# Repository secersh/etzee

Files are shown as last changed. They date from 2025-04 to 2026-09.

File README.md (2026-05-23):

# etzee

etzee is an open modular input-device ecosystem. It combines keyboards, utility modules, magnetic pogo-pin connectors, local displays, haptics, and firmware that can discover and communicate across connected modules.

The project is early and hardware-heavy. The current active board is B11; M0 and M9 are planned modules.

## Devices

| Device | Type | Status | Notes |
|---|---|---|---|
| B11 | Primary keyboard board | Active | Split or monoblock keyboard, 5/6 columns per half, switch-family PCB variants |
| M0 | Module | Planned | USB-C module with haptic dial and round touch display |
| M9 | Module | Planned | USB-C 3x3 mechanical keypad with display |

## B11

B11 is the first primary etzee keyboard. Current design goals:

- split or monoblock use
- Bluetooth-first firmware target
- hot-swappable switch carriers
- integrated dot-matrix display on switch plates
- south-facing per-key LEDs
- magnetic pogo-pin module connectors
- 5-column and 6-column half variants
- MX, Choc v2, and KS-33 switch-family variants
- generated KiCad PCB files from tracked MCAD-derived outlines

Current B11 docs:

- [switch compatibility](docs/b11/switch-compatibility.md)
- [switch profiles](docs/b11/switch-profiles.md)
- [keycap compatibility](docs/b11/keycap-compatibility.md)

## Repository Layout

```text
.github/workflows/          GitHub Actions workflows
docs/b11/                   B11 hardware compatibility and profile docs
docs/firmware/              firmware and protocol docs
firmware/                   firmware workspaces
hardware/b11/ecad/          B11 KiCad projects and generated boards
hardware/b11/mcad/          B11 MCAD export config and PCB outlines
hardware/b11/tools/         B11 PCB generation/update tools
hardware/tools/             shared hardware tooling
lib/                        shared KiCad footprints, 3D models, datasheets
```

## Generated PCB Workflow

B11 generated boards are updated through one batch script:

```sh
/Applications/KiCad/KiCad.app/Contents/Frameworks/Python.framework/Versions/Current/bin/python3 hardware/b11/tools/update-pcbs.py --manufacturer jlcpcb --dry-run
```

Remove `--dry-run` to update generated PCB files locally. The updater can generate PCB outlines, place switch sockets, place switch LEDs, place display LEDs, apply manufacturer stackups, and generate manufacturer design rules.

Current generated B11 PCB variants:

| Family | Columns | Boards |
|---|---|---|
| MX | 5, 6 | `LSP`, `RSP`, `LSC`, `RSC` |
| CHOC-V2 | 5, 6 | `LSP`, `RSP`, `LSC`, `RSC` |
| KS-33 | 5, 6 | `LSP`, `RSP`, `LSC`, `RSC` |

Board names use:

```text
ETZ-B11-{board_code}-{columns}-{switch_family}.kicad_pcb
```

Example:

```text
ETZ-B11-LSP-5-KS-33.kicad_pcb
```

## MCAD Exports

B11 MCAD export inputs are defined in [hardware/b11/mcad/parts.yaml](hardware/b11/mcad/parts.yaml). The GitHub workflow exports common parts once and matrix parts once per board variant:

- `5-MX`, `6-MX`
- `5-CHOC-V2`, `6-CHOC-V2`
- `5-KS-33`, `6-KS-33`

PCB outline DXFs live under:

```text
hardware/b11/mcad/pcb-outlines/{MX,CHOC-V2,KS-33}/
```

## Firmware

Firmware is based around ZMK-compatible targets. The htoyto protocol is the project-specific communication concept for inter-module discovery and messaging.

- [htoyto protocol overview](docs/firmware/htoyto.md)

## Contributing

See [CONTRIBUTING.md](CONTRIBUTING.md). The short version: keep generated files reproducible, keep hardware changes scoped, and run the relevant dry-runs before opening a pull request.

For discussion and implementation feedback, join the etzee Discord:

https://discord.gg/y3pcSCghcg

## License

This repository uses different open licenses for different material types. See [LICENSE.md](LICENSE.md) for the full licensing map.

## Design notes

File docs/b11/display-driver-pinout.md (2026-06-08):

<!-- SPDX-License-Identifier: CC-BY-4.0 -->

# B11 Display Driver Pinout

The B11 display matrix uses an IS31FL3741A LED driver and a 39 x 7 active LED
matrix. The driver supports 39 CS lines and 9 SW lines; `SW8` and `SW9` are
unused on the rev1 DSP module.

## IS31FL3741A Matrix Pins

The IS31FL3741A QFN-60 matrix pins are clustered like this:

| Package area | Pins | Nets |
| --- | --- | --- |
| Left/top side | 1-6 | `LED_CS34` .. `LED_CS39` |
| Bottom side | 16-24 | `LED_SW1` .. `LED_SW9` |
| Bottom/right corner | 26-30 | `LED_CS1` .. `LED_CS5` |
| Right side | 31-35, 37-45 | `LED_CS6` .. `LED_CS19` |
| Top/right side | 46-54, 56-60 | `LED_CS20` .. `LED_CS33` |

Pins `7`-`15`, `25`, `36`, `55`, and exposed pad `61` are driver control,
power, or ground pins and are not routed through the display board
castellations.

## Display Module Castellated Pads

The rev1 display LED matrix board uses 46 castellated LED pads along the two
long side edges. These are board-to-board solder pads, not a separate
connector. Pad numbers walk counter-clockwise around the side castellations:

| Edge pads | Physical group | Nets |
| --- | --- | --- |
| 1-11 | left/top | `LED_CS29` .. `LED_CS19` |
| 12-23 | left/bottom | `LED_CS18`, `LED_CS16` .. `LED_CS6` |
| 24-35 | right/bottom | `LED_CS5` .. `LED_CS1`, `LED_SW7` .. `LED_SW1` |
| 36-46 | right/top | `LED_CS17`, `LED_CS39` .. `LED_CS30` |

This package-oriented map is intended to make SP-side fanout from the
IS31FL3741A easier. The map is mirrored left-to-right so the driver can sit
near the center/right of the SP board and fan out mostly to the nearer
right-side castellated groups.

The ALS signals use four separate top-edge castellated pads, left-to-right:
`ALS_VDD`, `ALS_SCL`, `ALS_SDA`, `ALS_GND`.

The source of truth for generated tooling is
`hardware/b11/tools/placement/display_pinout.py`.

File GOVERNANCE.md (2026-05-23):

# Governance

etzee is maintained by its founders as peers. Current founder-maintainers are listed in `MAINTAINERS.md`.

## Decision Making

Major project decisions are made by founder consensus. Decisions are made pragmatically around:

- reproducible hardware and firmware outputs
- manufacturability
- maintainable tooling
- clear licensing and attribution
- compatibility with the current B11, M0, and M9 roadmap

Maintainers may decline or defer changes that are useful but outside the current project scope.

## Founder-Maintainer Responsibilities

Founder-maintainers jointly share responsibility for:

- reviewing and merging pull requests
- keeping generated files reproducible
- setting release and manufacturing direction
- product direction
- hardware and firmware architecture
- licensing
- enforcing the code of conduct
- coordinating security disclosures

Specific implementation areas may be handled by whoever has the relevant context for that change.

## Contributor Responsibilities

Contributors are expected to:

- keep pull requests focused
- explain hardware, firmware, or tooling tradeoffs clearly
- update docs when behavior or interfaces change
- preserve license and attribution notices

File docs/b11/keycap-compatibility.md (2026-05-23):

# B11 Keycap Compatibility

B11 keycaps must use MX-compatible stems. This keeps the keycap interface common across the supported switch families, including MX, Choc v2, and KS-33 variants.

| Keycap requirement | Value |
|---|---|
| Stem | MX-compatible cross stem |
| Switch grid pitch | 19.2 mm x 19.2 mm |
| Supported B11 switch families | `MX`, `CHOC-V2`, `KS-33` |

Low-profile switch variants can still use MX-stem keycaps, but cap height, skirt clearance, and travel clearance need to be checked against the selected switch family and enclosure geometry.

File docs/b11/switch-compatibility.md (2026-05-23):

# B11 Switch Compatibility

B11 currently generates separate PCB variants per switch family. The family name is used in ECAD board paths, MCAD PCB outline paths, and MCAD release artifact suffixes.

| Switch family | Compatible switches | Profile | Socket footprint | PCB family |
|---|---|---|---|---|
| MX | Cherry MX and common MX-compatible switches from Kailh, Gateron, and others | Normal | `PG151101S11` | `MX` |
| CHOC-V2 | Kailh Choc v2 / PG1353 | Low | `CPG135001S30` | `CHOC-V2` |
| KS-33 | Gateron KS-33 / KS-2P02B01-01-a | Low | `KS-2P02B01-01-a` | `KS-33` |

Generated B11 switch PCB variants use this layout:

| Family | ECAD boards | PCB outlines | MCAD artifact suffixes |
|---|---|---|---|
| MX | `hardware/b11/ecad/MX/` | `hardware/b11/mcad/pcb-outlines/MX/` | `5-MX`, `6-MX` |
| CHOC-V2 | `hardware/b11/ecad/CHOC-V2/` | `hardware/b11/mcad/pcb-outlines/CHOC-V2/` | `5-CHOC-V2`, `6-CHOC-V2` |
| KS-33 | `hardware/b11/ecad/KS-33/` | `hardware/b11/mcad/pcb-outlines/KS-33/` | `5-KS-33`, `6-KS-33` |

All current B11 switch variants use a 19.2 mm x 19.2 mm switch grid pitch. Switch-specific footprints, plate geometry, and board stackups are handled by the B11 PCB generation tools.

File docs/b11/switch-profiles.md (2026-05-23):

# B11 Switch Profiles

Mechanical stackup parameters per B11 switch family. These values drive the OnShape switch-family configurations and the generated PCB variants.

| Parameter | MX | CHOC-V2 | KS-33 |
|---|----|---|---|
| Switch plate mechanical thickness (mm) | 1.5-1.9 | 1.65 | 1.2 |
| Switch plate PCB order thickness (mm) | 1.6 | 1.6 | 1.2 |
| Carrier board mechanical thickness (mm) | 1.6 | 1.6 | 1.5-1.6 |
| Carrier board PCB order thickness (mm) | 1.6 | 1.6 | 1.6 |
| Top plate to top carrier offset (mm) | 5.0 | 2.2 | 2.5 |

The PCB order thickness rows are the rounded manufacturer thicknesses used by `hardware/b11/tools/config.py`.

Offset is the vertical distance from the top surface of the switch plate to the top surface of the carrier board.

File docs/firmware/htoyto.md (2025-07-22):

# htoyto Protocol – Integration Overview

This document outlines the detailed structure for integrating the **htoyto** protocol ("hello to you too") into a ZMK-based firmware stack. The protocol enables UART-based inter-module communication between a sender and one or more receivers, with rising-edge interrupts for handshake initiation.

> ℹ️ Note: This implementation is ZMK-specific and relies on ZMK's event system. If you plan to reuse `htoyto` in pure Zephyr projects, consider creating a separate generic backend.

---

## 🧽 Node Roles Overview

* `origin` — initiates communication (**1×** occurrence per htoyto chain)
* `bridge` — relays data between nodes (**0 or more** per chain)
* `terminal` — receives and handles commands (**1×** occurrence per chain)

### Visual Topology

```mermaid
graph LR
    Origin((origin)) -->|UART + dR| B1{{bridge}}
    B1 -->|UART + dR| B2{{bridge}}
    B2 -->|UART| Terminal((terminal))
```

> 💡 The topology follows a left-to-right convention. Only the left-most node requires a `dr-gpios` interrupt pin. Bridges pass through data and may generate their own responses.

---

## 📦 Data Frames

### Supported Packet Types

| Frame | Description |
| --- | --- |
| `HLO <node_id>` | Initiates handshake from origin |
| `IAM <node_id>` | Identity declaration from terminal or bridge |
| `EST <node_id>` | Establish link — sent by both origin and terminal to confirm connection |
| `DKW <message>` | Rejection — origin to terminal with reason (e.g., unknown node) |
| `TLK <source,target,data>` | Application-level message |
| `ACK <ref>` (optional) | Acknowledgment of a `TLK` frame |

> 💡 `DKW` is always sent by the origin to a node it refuses to accept. `EST` completes a handshake only if echoed from both sides.

---

## 🤝 Handshake: Node Lifecycle

### ✅ Successful Node Adding

**Sequence (Origin ➔ Terminal)**

1. Origin detects rising edge on `dR` line
2. Origin sends: `HLO <origin_id>`
3. Terminal responds: `IAM <terminal_id>`
4. Origin sends: `EST <origin_id>`
5. Terminal sends: `EST <terminal_id>`

**Emitted Events**

* Origin emits: `HTOYTO_EVENT_NODE_ADDED`
* Terminal emits: `HTOYTO_EVENT_NODE_ADDED`

---

### ✅ Successful Node Removal

**Sequence (Origin ➔ Terminal)**

1. Origin detects **falling edge** on `dR` line (physical disconnect or deliberate teardown)

**Emitted Events**

* Origin emits: `HTOYTO_EVENT_NODE_REMOVED`
* Terminal emits: `HTOYTO_EVENT_NODE_REMOVED`

---

### ❌ Failure: Terminal Not Supported

**Sequence**

1. Origin sends: `HLO <origin_id>`
2. Terminal responds: `IAM <terminal_id>`
3. Origin sends: `DKW <reason>`

**Emitted Events**

* Origin emits: `HTOYTO_EVENT_NODE_ADDED_FAILED`
* Terminal emits: `HTOYTO_EVENT_NODE_ADDED_FAILED`

---

### ❌ Failure: Timeout

#### Sub-case A: No IAM from Terminal

* Origin sends: `HLO <origin_id>`
* ⏱️ Terminal does not respond with `IAM` in \[xx ms]

**Emitted Events**

* Origin emits: `HTOYTO_EVENT_NODE_ADDED_FAILED`
* Terminal emits: `HTOYTO_EVENT_NODE_ADDED_FAILED`

#### Sub-case B: No EST from Terminal

* Origin sends: `EST <origin_id>`
* ⏱️ Terminal does not respond with `EST <terminal_id>` in \[xx ms]

**Emitted Events**

* Origin emits: `HTOYTO_EVENT_NODE_ADDED_FAILED`
* Terminal emits: `HTOYTO_EVENT_NODE_ADDED_FAILED`

#### Sub-case C: No EST from Origin

* Terminal sends: `IAM <terminal_id>`
* ⏱️ Origin does not respond with `EST <origin_id>` in \[xx ms]

**Emitted Events**

* Origin emits: `HTOYTO_EVENT_NODE_ADDED_FAILED`
* Terminal emits: `HTOYTO_EVENT_NODE_ADDED_FAILED`

---

## 🗂️ Project Structure

### 1. Device Tree Files

#### DTS Overlay

* **Path:** `app/boards/arm/etzee/left.overlay` (origin) and `app/boards/arm/etzee/right.overlay` (terminal)
* **Purpose:** Defines `htoyto` device nodes per side

```dts
/ {
    htoyto0: htoyto {
        compatible = "etzee,htoyto-zmk";
        status = "okay";
        role = "origin"; /* on left side */
        uart = <&uart0>;
        dr-gpios = <&gpio1 11 (GPIO_ACTIVE_HIGH | GPIO_PULL_DOWN)>;
        node-id = "left_leg";
    };
};
```

```dts
/ {
    htoyto0: htoyto {
        compatible = "etzee,htoyto-zmk";
        status = "okay";
        role = "terminal"; /* on right side */
        uart = <&uart0>;
        node-id = "right_leg";
    };
};
```

#### YAML Binding

* **Path:** `app/dts/bindings/htoyto/htoyto.yaml`
* **Purpose:** Describes properties (`uart`, `dr-gpios`, `role`, etc.)

```yaml
compatible: "etzee,htoyto-zmk"

include: base.yaml

properties:
  uart:
    type: phandle
    required: true
    description: UART device used for htoyto communication

  dr-gpios:
    type: phandle-array
    required: false
    description: >
      GPIO pin used for rising edge interrupt (dR line).
      Required only for origin and bridge roles.
      Although only one pin is used, Zephyr requires 'gpios' to be plural
      because the property value is a structured array of controller, pin, and flags.

  role:
    type: string
    required: true
    enum:
      - origin
      - bridge
      - terminal
    description: >
      Role of the htoyto node:
        - origin: initiates communication (left-facing connection)
        - bridge: forwards from left to right (middle node)
        - terminal: receives commands (right-facing connection)

  node-id:
    type: string
    required: true
    description: >
      A unique identifier for the node in the htoyto network.
      Used to route or trigger logic based on physical orientation or connection topology.
```

> 💡 In physical design, a node with pogo pins on **both sides** can act as a **bridge**: a terminal on the left and an origin on the right. This makes `node-id` essential for identification and orchestration.

---

### 2. C Header and Source Files

#### Header File

* **Path:** `app/include/htoyto/htoyto.h`
* **Purpose:** Public API, status enums, macros, event declarations

#### Source File

* **Path:** `app/src/htoyto/htoyto.c`
* **Purpose:** Handles init, handshake logic, GPIO ISR, UART read/write, event emission, and command callback registration

---

### 3. Kconfig Integration

#### Kconfig File

* **Path:** `app/src/htoyto/Kconfig`

```kconfig
config HTOYTO_ENABLED
    bool "Enable htoyto protocol"
    default y
    help
      Enables the etzee htoyto protocol support for UART-based inter-module communication.
```

#### Include in Tree

* **Path:** `app/src/Kconfig`

```kconfig
source "src/htoyto/Kconfig"
```

---

### 4. CMake Integration

#### Main Include

* **Path:** `app/src/CMakeLists.txt`

```cmake
add_subdirectory(htoyto)
```

#### htoyto-specific File

* **Path:** `app/src/htoyto/CMakeLists.txt`

```cmake
zephyr_library_sources(htoyto.c events/event.c)
zephyr_include_directories(${CMAKE_CURRENT_SOURCE_DIR}/../../include)
```

---

### 5. Event System

#### Event Header

* **Path:** `app/include/htoyto/events/event.h`
* **Purpose:** Defines `htoyto_event` structure and event types:

```c
enum htoyto_event_type {
    HTOYTO_EVENT_NODE_ADDED,
    HTOYTO_EVENT_NODE_ADDED_FAILED,
    HTOYTO_EVENT_NODE_REMOVED,
    HTOYTO_EVENT_TLK_RECEIVED,
    HTOYTO_EVENT_ACK_RECEIVED,
    HTOYTO_EVENT_ACK_TIMEOUT
};
```

These events allow communication and state changes to propagate across the system. You may attach listeners to trigger animation, sound, or haptic behavior via a story board system.

---

### 6. Board Setup (Custom Board)

If building a custom board:

* Use `left.overlay` and `right.overlay` under `app/boards/arm/etzee/`
* Add UART, GPIO, and htoyto config to corresponding `.conf` files

---

### 7. Build Config

#### Conf File

* **Path:** `app/boards/arm/etzee/<left|right>.conf`

```conf
CONFIG_SERIAL=y
CONFIG_UART_INTERRUPT_DRIVEN=y
CONFIG_HTOYTO_ENABLED=y
CONFIG_HTOYTO_UART_RX_TIMEOUT_MS=100
CONFIG_HTOYTO_HANDSHAKE_TIMEOUT_MS=200
CONFIG_HTOYTO_MAX_NODE_ID_LENGTH=16
```

---

### ✅ Summary of File Locations

| Type | Path | |
| --- | --- | - |
| DTS Overlay | `app/boards/arm/etzee/left.overlay`, `right.overlay` | |
| YAML Binding | `app/dts/bindings/htoyto/htoyto.yaml` | |
| Header File | `app/include/htoyto/htoyto.h` | |
| Source File | `app/src/htoyto/htoyto.c` | |
| Kconfig | `app/src/htoyto/Kconfig` | |
| CMakeLists.txt | `app/src/htoyto/CMakeLists.txt` | |
| Event Header | `app/include/htoyto/events/event.h` | |
| Event Source | `app/src/htoyto/events/event.c` | |
| Build Config | `app/boards/arm/etzee/<left`, `right>.conf` | |

---

## 🔮 Future Expansion: Story Board Engine

You plan to integrate a second hardware module (dot matrix display, ambient light sensor, beeper) that reacts to htoyto events. A third software component — the **story board engine** — will:

* React to `htoyto_event` events (e.g., `NODE_ADDED`)
* Trigger and play storyboards, defined as animations (with keyframes) + optional audio or haptic effects
* Tailor the experience depending on the `node-id`

This system will allow rich interactions like:

* 🎮 Playing light/audio animations when a certain module connects
* 🎧 Triggering beeps or tones synced to keyframe animation
* 🪏 Optionally driving haptics to complete the effect

This design allows creative UI/UX behaviors inside the firmware, making every module connection feel alive.

Stay tuned for a dedicated story board architecture document.

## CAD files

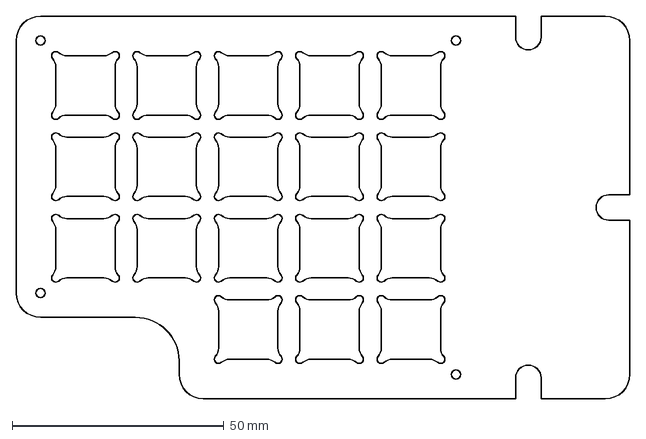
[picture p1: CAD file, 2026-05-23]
hardware/b11/mcad/pcb-outlines/CHOC-V2/ETZ-B11-LSP-5-CHOC-V2.dxf
144.7 x 90.2 mm

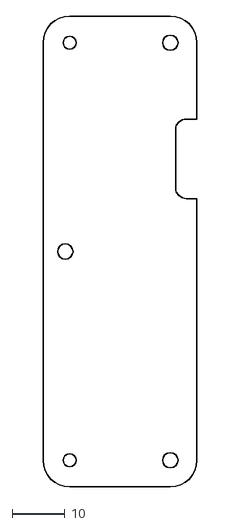
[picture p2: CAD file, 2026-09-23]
hardware/b11/mcad/pcb-outlines/common/ETZ-B11-RLB.dxf
29.0 x 88.8

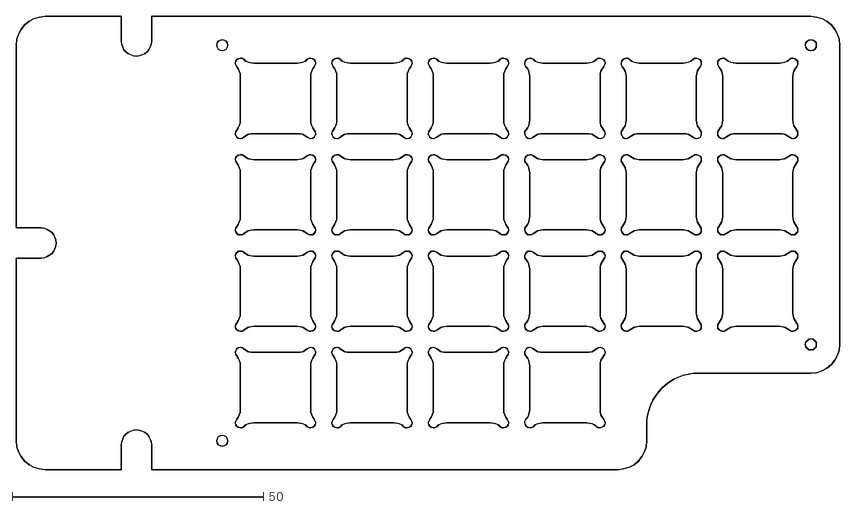
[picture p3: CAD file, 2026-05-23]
hardware/b11/mcad/pcb-outlines/KS-33/ETZ-B11-RSP-6-KS-33.dxf
163.9 x 90.2

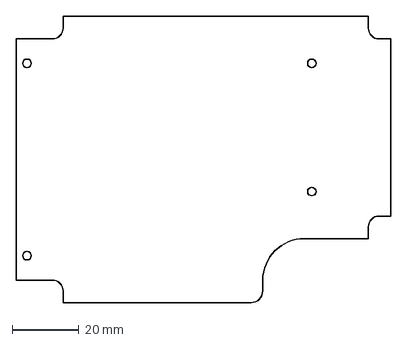
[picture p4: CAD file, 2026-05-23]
hardware/b11/mcad/pcb-outlines/MX/ETZ-B11-RSC-5-MX.dxf
112.3 x 85.8 mm

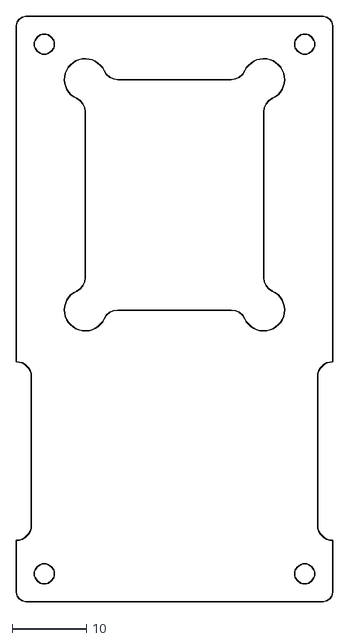
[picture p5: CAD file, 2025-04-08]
manufacturing/Keyboard parts - Display PCB.dxf
42.5 x 78.7

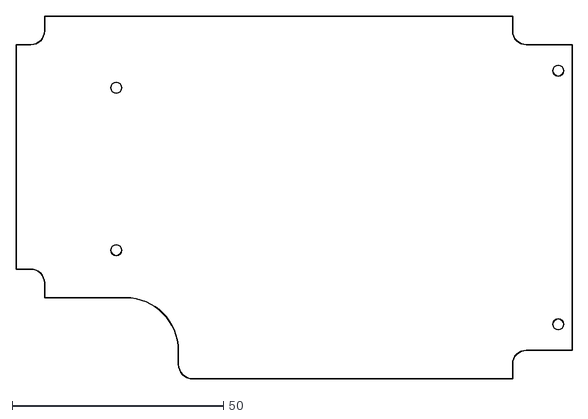
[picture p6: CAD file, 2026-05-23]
hardware/b11/mcad/pcb-outlines/CHOC-V2/ETZ-B11-LSC-6-CHOC-V2.dxf
131.5 x 85.8

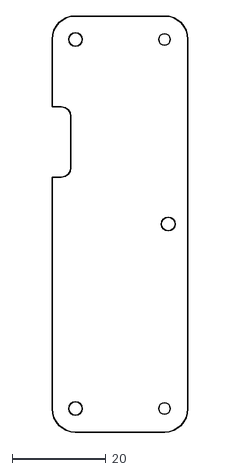
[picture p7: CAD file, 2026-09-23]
hardware/b11/mcad/pcb-outlines/common/ETZ-B11-LLB.dxf
29.0 x 88.8

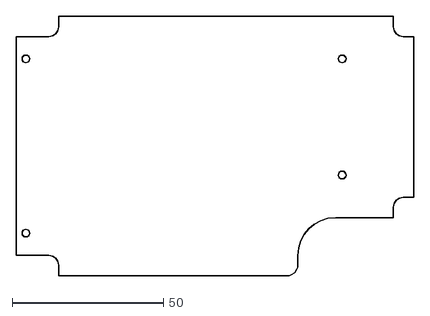
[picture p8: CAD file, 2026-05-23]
hardware/b11/mcad/pcb-outlines/MX/ETZ-B11-RSC-6-MX.dxf
131.5 x 85.8

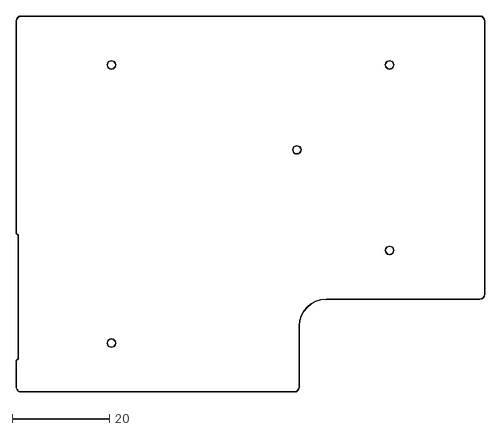
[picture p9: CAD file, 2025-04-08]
manufacturing/Keyboard parts - R PCB.dxf
96.3 x 77.2

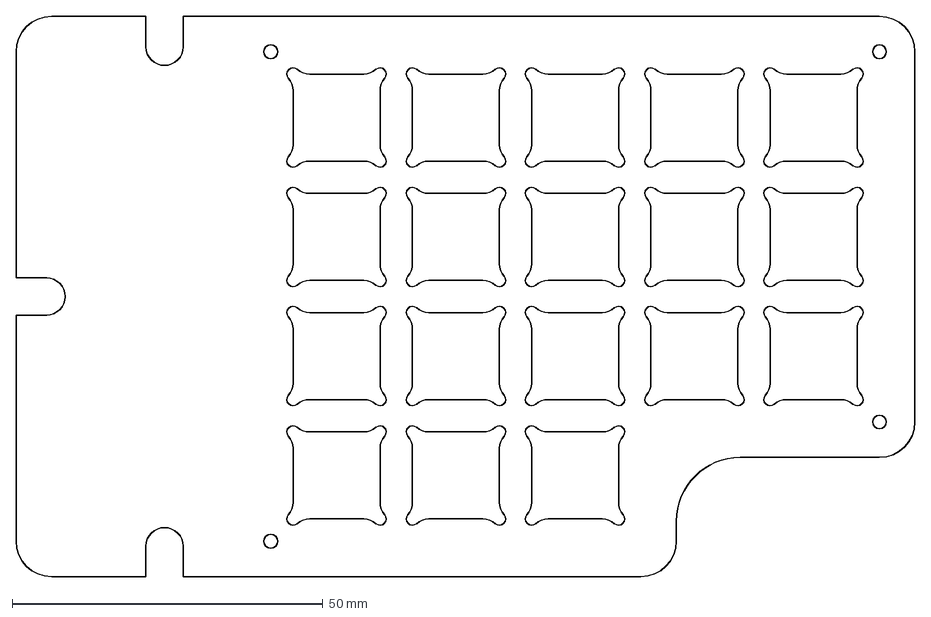
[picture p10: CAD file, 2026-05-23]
hardware/b11/mcad/pcb-outlines/CHOC-V2/ETZ-B11-RSP-5-CHOC-V2.dxf
144.7 x 90.2 mm

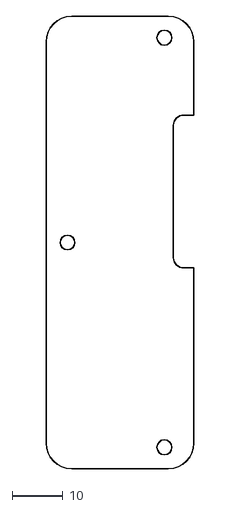
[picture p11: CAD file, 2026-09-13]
hardware/b11/mcad/pcb-outlines/common/ETZ-B11-LGB-R.dxf
29.0 x 88.8

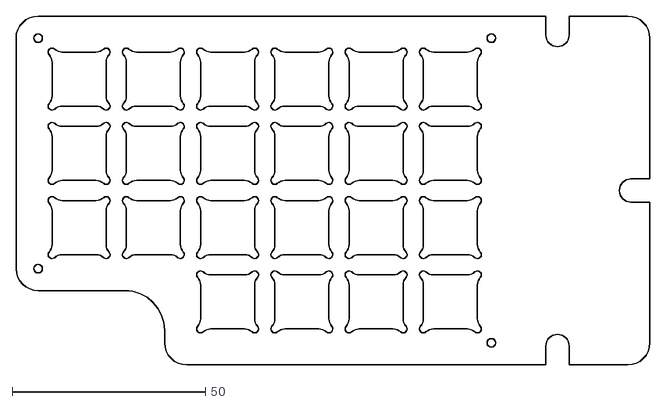
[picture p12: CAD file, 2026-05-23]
hardware/b11/mcad/pcb-outlines/MX/ETZ-B11-LSP-6-MX.dxf
163.9 x 90.2

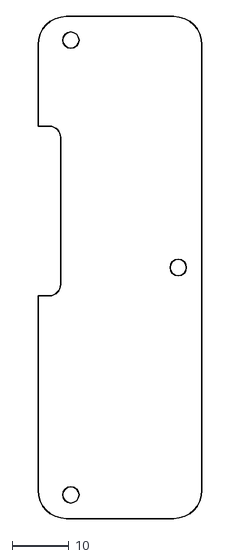
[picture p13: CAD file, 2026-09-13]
hardware/b11/mcad/pcb-outlines/common/ETZ-B11-LGB-L.dxf
29.0 x 88.8

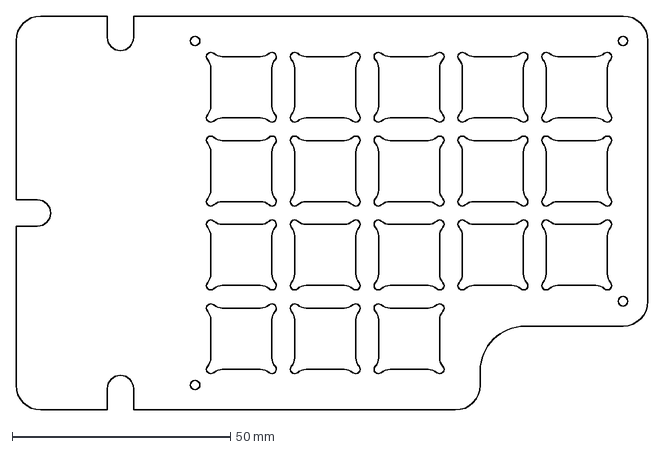
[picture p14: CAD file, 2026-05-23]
hardware/b11/mcad/pcb-outlines/MX/ETZ-B11-RSP-5-MX.dxf
144.7 x 90.2 mm

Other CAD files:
hardware/b11/mcad/pcb-outlines/CHOC-V2/ETZ-B11-LSC-5-CHOC-V2.dxf
hardware/b11/mcad/pcb-outlines/CHOC-V2/ETZ-B11-RSC-5-CHOC-V2.dxf
hardware/b11/mcad/pcb-outlines/KS-33/ETZ-B11-LSC-5-KS-33.dxf
hardware/b11/mcad/pcb-outlines/KS-33/ETZ-B11-RSC-5-KS-33.dxf
hardware/b11/mcad/pcb-outlines/MX/ETZ-B11-LSC-5-MX.dxf
hardware/b11/mcad/pcb-outlines/MX/ETZ-B11-LSP-5-MX.dxf
hardware/b11/mcad/pcb-outlines/common/ETZ-B11-DSP.dxf

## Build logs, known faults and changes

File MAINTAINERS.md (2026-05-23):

# Maintainers

etzee is maintained by its founders as peers.

## Founders

- secersh
- kikiosvetnik

## Responsibilities

The founders jointly maintain:

- product direction
- hardware and firmware architecture
- releases
- licensing
- community standards
- repository access

Specific implementation areas may be handled by whoever has the relevant context for that change.

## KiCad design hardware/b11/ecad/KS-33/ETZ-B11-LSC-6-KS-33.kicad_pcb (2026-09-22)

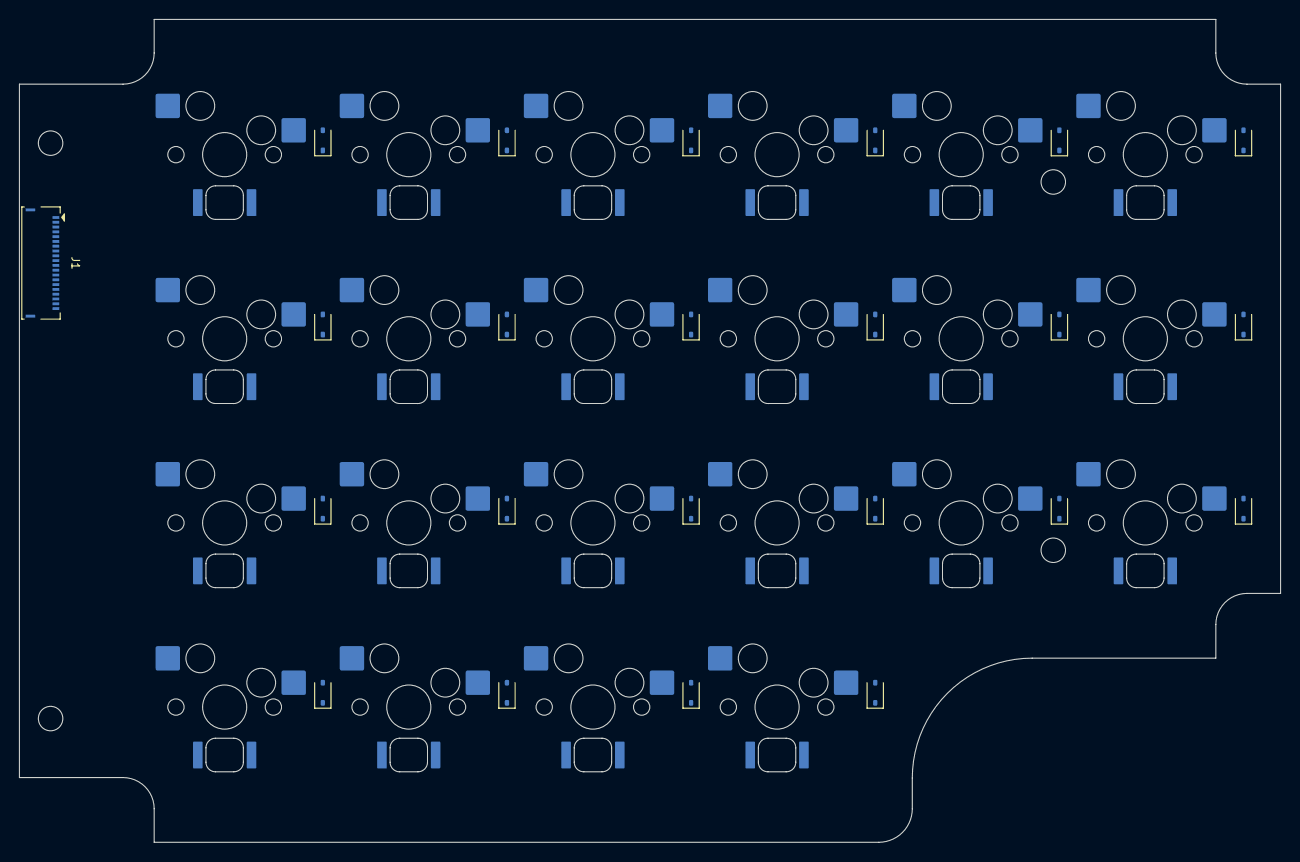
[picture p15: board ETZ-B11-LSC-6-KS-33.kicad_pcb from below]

Board: 2 copper layers, 131.5 x 85.8 mm, 67 parts (23 on the bottom side), 32 nets, no tracks yet.

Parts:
D1, D2, D3, D4, D5, D6, D7, D8, D9, D10, D11, D12, D13, D14, D15, D16, D17, D18, D19, D20, D21, D22: 1N4148WS
J1: 503480-2000
LED1, LED2, LED3, LED4, LED5, LED6, LED7, LED8, LED9, LED10, LED11, LED12, LED13, LED14, LED15, LED16, LED17, LED18, LED19, LED20, LED21, LED22: 6028_LED
SW1, SW2, SW3, SW4, SW5, SW6, SW7, SW8, SW9, SW10, SW11, SW12, SW13, SW14, SW15, SW16, SW17, SW18, SW19, SW20, SW21, SW22: KS-2P02B01-01-a

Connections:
COL0: D1.1, D7.1, D13.1
COL1: D2.1, D8.1, D14.1
COL2: D3.1, D9.1, D15.1, D19.1
COL3: D4.1, D10.1, D16.1, D20.1
COL4: D5.1, D11.1, D17.1, D21.1
COL5: D6.1, D12.1, D18.1, D22.1
ROW0: SW1.1, SW2.1, SW3.1, SW4.1, SW5.1, SW6.1
ROW1: SW7.1, SW8.1, SW9.1, SW10.1, SW11.1, SW12.1
ROW2: SW13.1, SW14.1, SW15.1, SW16.1, SW17.1, SW18.1
ROW3: SW19.1, SW20.1, SW21.1, SW22.1
SW1: D1.2, SW1.2
SW2: D2.2, SW2.2
SW3: D3.2, SW3.2
SW4: D4.2, SW4.2
SW5: D5.2, SW5.2
SW6: D6.2, SW6.2
SW7: D7.2, SW7.2
SW8: D8.2, SW8.2
SW9: D9.2, SW9.2
SW10: D10.2, SW10.2
SW11: D11.2, SW11.2
SW12: D12.2, SW12.2
SW13: D13.2, SW13.2
SW14: D14.2, SW14.2
SW15: D15.2, SW15.2
SW16: D16.2, SW16.2
SW17: D17.2, SW17.2
SW18: D18.2, SW18.2
SW19: D19.2, SW19.2
SW20: D20.2, SW20.2
SW21: D21.2, SW21.2
SW22: D22.2, SW22.2

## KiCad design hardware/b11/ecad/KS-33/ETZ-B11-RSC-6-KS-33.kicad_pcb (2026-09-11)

Board: 2 copper layers, 44 parts (0 on the bottom side), 10 nets, no tracks yet.

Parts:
LED1, LED2, LED3, LED4, LED5, LED6, LED7, LED8, LED9, LED10, LED11, LED12, LED13, LED14, LED15, LED16, LED17, LED18, LED19, LED20, LED21, LED22: 6028_LED
SW1, SW2, SW3, SW4, SW5, SW6, SW7, SW8, SW9, SW10, SW11, SW12, SW13, SW14, SW15, SW16, SW17, SW18, SW19, SW20, SW21, SW22: KS-2P02B01-01-a

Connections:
COL0: SW1.2, SW7.2, SW13.2
COL1: SW2.2, SW8.2, SW14.2
COL2: SW3.2, SW9.2, SW15.2, SW19.2
COL3: SW4.2, SW10.2, SW16.2, SW20.2
COL4: SW5.2, SW11.2, SW17.2, SW21.2
COL5: SW6.2, SW12.2, SW18.2, SW22.2
ROW0: SW1.1, SW2.1, SW3.1, SW4.1, SW5.1, SW6.1
ROW1: SW7.1, SW8.1, SW9.1, SW10.1, SW11.1, SW12.1
ROW2: SW13.1, SW14.1, SW15.1, SW16.1, SW17.1, SW18.1
ROW3: SW19.1, SW20.1, SW21.1, SW22.1

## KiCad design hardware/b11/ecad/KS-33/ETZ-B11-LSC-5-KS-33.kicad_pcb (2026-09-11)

Board: 2 copper layers, 36 parts (0 on the bottom side), 9 nets, no tracks yet.

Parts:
LED1, LED2, LED3, LED4, LED5, LED6, LED7, LED8, LED9, LED10, LED11, LED12, LED13, LED14, LED15, LED16, LED17, LED18: 6028_LED
SW1, SW2, SW3, SW4, SW5, SW6, SW7, SW8, SW9, SW10, SW11, SW12, SW13, SW14, SW15, SW16, SW17, SW18: KS-2P02B01-01-a

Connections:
COL0: SW1.2, SW6.2, SW11.2
COL1: SW2.2, SW7.2, SW12.2
COL2: SW3.2, SW8.2, SW13.2, SW16.2
COL3: SW4.2, SW9.2, SW14.2, SW17.2
COL4: SW5.2, SW10.2, SW15.2, SW18.2
ROW0: SW1.1, SW2.1, SW3.1, SW4.1, SW5.1
ROW1: SW6.1, SW7.1, SW8.1, SW9.1, SW10.1
ROW2: SW11.1, SW12.1, SW13.1, SW14.1, SW15.1
ROW3: SW16.1, SW17.1, SW18.1

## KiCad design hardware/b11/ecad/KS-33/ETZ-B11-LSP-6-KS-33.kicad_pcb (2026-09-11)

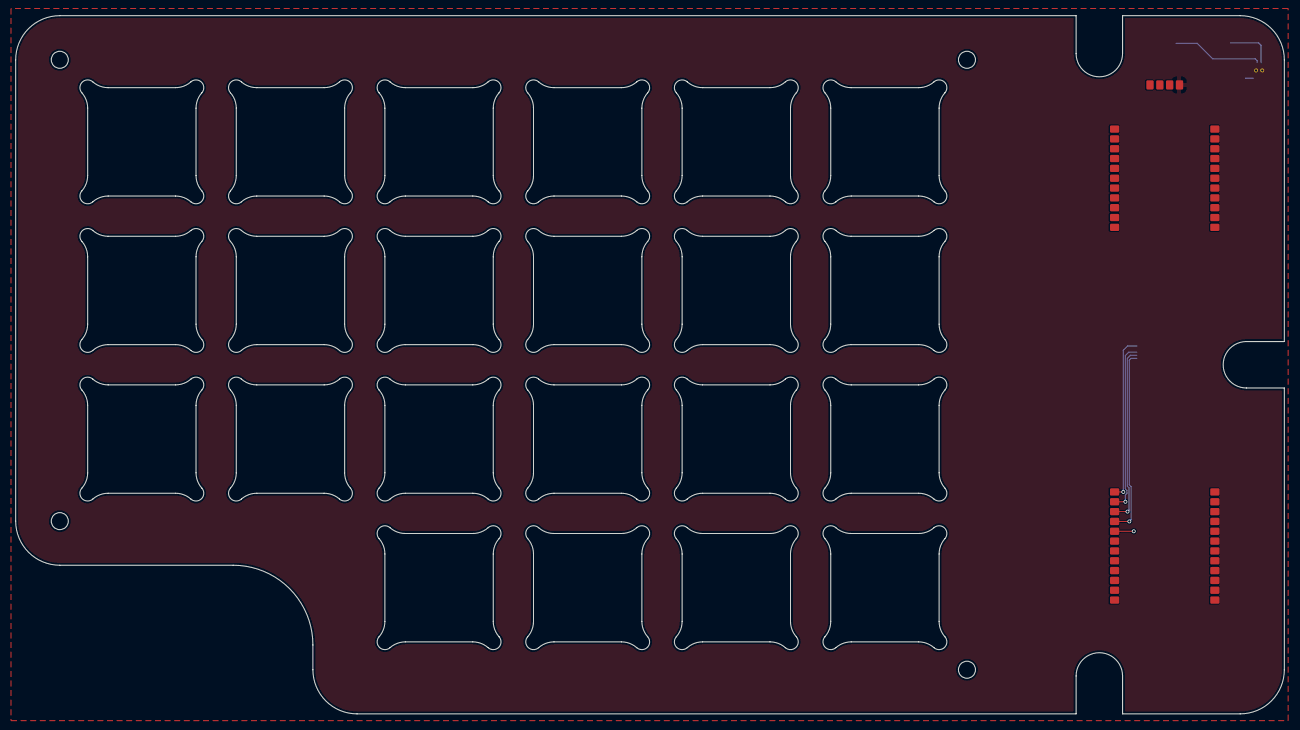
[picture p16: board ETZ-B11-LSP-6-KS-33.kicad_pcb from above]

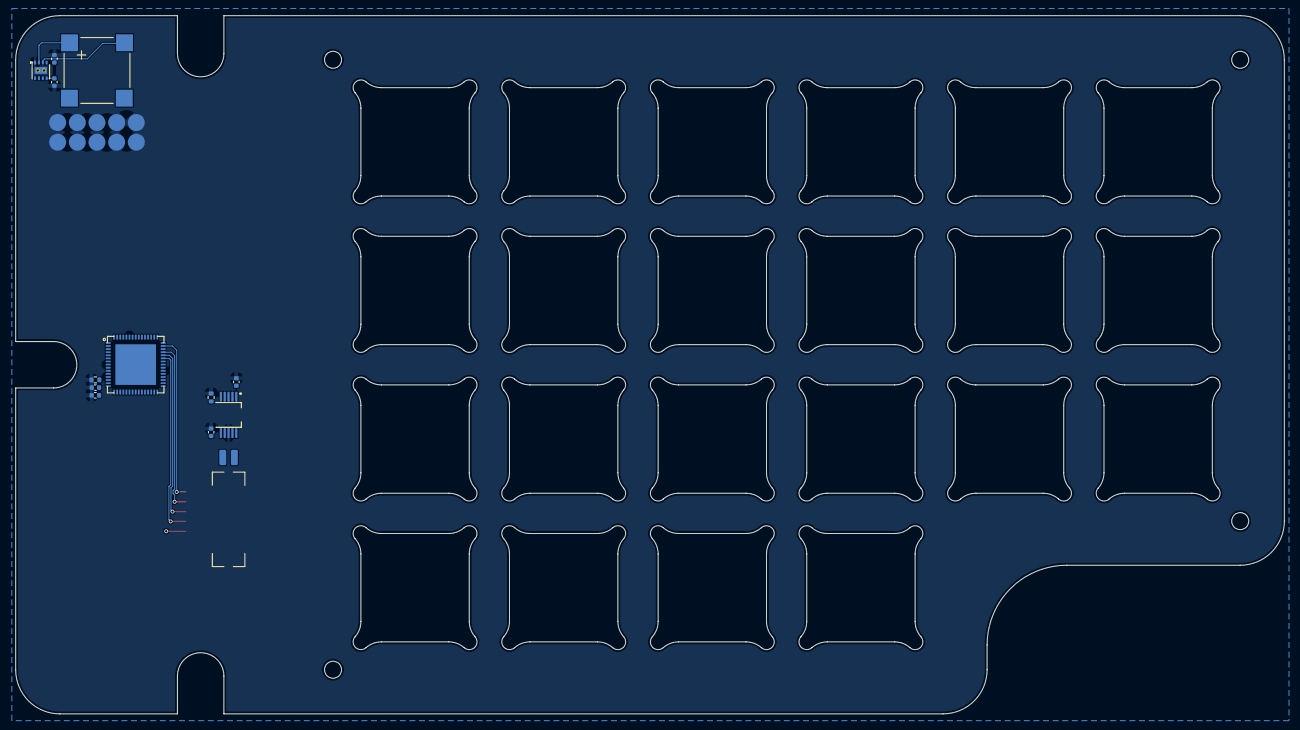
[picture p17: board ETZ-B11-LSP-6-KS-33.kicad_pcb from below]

Board: 2 copper layers, 163.9 x 90.2 mm, 15 parts (14 on the bottom side), 61 nets.

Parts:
BZ1: KLJ-8530-3627
C_BUZZ1: 0.1uF
C_BUZZ2: 4.7uF
C_DSP1: 0.1uF
C_DSP2: 4.7uF
C_HAPTIC1: 1uF
C_HAPTIC2: 0.1uF
J_LOGIC1: POGO-PADS-2X5-P2.54
M_LRA1: VLV041235L-L20
R_DSP1: 20k
R_HAPTIC1: 100k
U_BUZZ1: DRV8837DSGR
U_DSP1: IS31FL3741A; IS31FL3741A-QFN-60-7x7
U_DSPMOD1: ETZ-B11-DSP
U_HAPTIC1: DRV2605LDGSR

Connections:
BUZZ_IN1: J_LOGIC1.8, U_BUZZ1.6
BUZZ_IN2: J_LOGIC1.9, U_BUZZ1.5
BUZZ_OUT1: BZ1.1, U_BUZZ1.3
BUZZ_OUT2: BZ1.2, U_BUZZ1.2
DISP_SDB: J_LOGIC1.6, U_DSP1.11
DRV2605_REG: C_HAPTIC1.1, U_HAPTIC1.1
GND: C_BUZZ1.2, C_BUZZ2.2, C_DSP1.2, C_DSP2.2, C_HAPTIC1.2, C_HAPTIC2.2, J_LOGIC1.1, J_LOGIC1.10, R_DSP1.2, R_HAPTIC1.2, U_BUZZ1.4, U_BUZZ1.9, U_DSP1.8, U_DSP1.12, U_DSP1.36, U_DSP1.55, U_DSP1.61, U_DSPMOD1.A4, U_HAPTIC1.8
HAPTIC_EN: J_LOGIC1.7, R_HAPTIC1.1, U_BUZZ1.7, U_HAPTIC1.5
I2C_SCL: J_LOGIC1.4, U_DSP1.10, U_DSPMOD1.A2, U_HAPTIC1.2
I2C_SDA: J_LOGIC1.5, U_DSP1.9, U_DSPMOD1.A3, U_HAPTIC1.3
ISET: R_DSP1.1, U_DSP1.13
LED_CS1: U_DSP1.26, U_DSPMOD1.28
LED_CS2: U_DSP1.27, U_DSPMOD1.27
LED_CS3: U_DSP1.28, U_DSPMOD1.26
LED_CS4: U_DSP1.29, U_DSPMOD1.25
LED_CS5: U_DSP1.30, U_DSPMOD1.24
LED_CS6: U_DSP1.31, U_DSPMOD1.23
LED_CS7: U_DSP1.32, U_DSPMOD1.22
LED_CS8: U_DSP1.33, U_DSPMOD1.21
LED_CS9: U_DSP1.34, U_DSPMOD1.20
LED_CS10: U_DSP1.35, U_DSPMOD1.19
LED_CS11: U_DSP1.37, U_DSPMOD1.18
LED_CS12: U_DSP1.38, U_DSPMOD1.17
LED_CS13: U_DSP1.39, U_DSPMOD1.16
LED_CS14: U_DSP1.40, U_DSPMOD1.15
LED_CS15: U_DSP1.41, U_DSPMOD1.14
LED_CS16: U_DSP1.42, U_DSPMOD1.13
LED_CS17: U_DSP1.43, U_DSPMOD1.36
LED_CS18: U_DSP1.44, U_DSPMOD1.12
LED_CS19: U_DSP1.45, U_DSPMOD1.11
LED_CS20: U_DSP1.46, U_DSPMOD1.10
LED_CS21: U_DSP1.47, U_DSPMOD1.9
LED_CS22: U_DSP1.48, U_DSPMOD1.8
LED_CS23: U_DSP1.49, U_DSPMOD1.7
LED_CS24: U_DSP1.50, U_DSPMOD1.6
LED_CS25: U_DSP1.51, U_DSPMOD1.5
LED_CS26: U_DSP1.52, U_DSPMOD1.4
LED_CS27: U_DSP1.53, U_DSPMOD1.3
LED_CS28: U_DSP1.54, U_DSPMOD1.2
LED_CS29: U_DSP1.56, U_DSPMOD1.1
LED_CS30: U_DSP1.57, U_DSPMOD1.46
LED_CS31: U_DSP1.58, U_DSPMOD1.45
LED_CS32: U_DSP1.59, U_DSPMOD1.44
LED_CS33: U_DSP1.60, U_DSPMOD1.43
LED_CS34: U_DSP1.1, U_DSPMOD1.42
LED_CS35: U_DSP1.2, U_DSPMOD1.41
LED_CS36: U_DSP1.3, U_DSPMOD1.40
LED_CS37: U_DSP1.4, U_DSPMOD1.39
LED_CS38: U_DSP1.5, U_DSPMOD1.38
LED_CS39: U_DSP1.6, U_DSPMOD1.37
LED_SW1: U_DSP1.16, U_DSPMOD1.35
LED_SW2: U_DSP1.17, U_DSPMOD1.34
LED_SW3: U_DSP1.18, U_DSPMOD1.33
LED_SW4: U_DSP1.19, U_DSPMOD1.32
LED_SW5: U_DSP1.20, U_DSPMOD1.31
LED_SW6: U_DSP1.21, U_DSPMOD1.30
LED_SW7: U_DSP1.22, U_DSPMOD1.29
LRA_OUTN: M_LRA1.2, U_HAPTIC1.9
LRA_OUTP: M_LRA1.1, U_HAPTIC1.7
SP_VDD: C_BUZZ1.1, C_BUZZ2.1, C_DSP1.1, C_DSP2.1, C_HAPTIC2.1, J_LOGIC1.3, U_BUZZ1.8, U_DSP1.14, U_DSP1.15, U_DSP1.25, U_DSPMOD1.A1
VBAT: J_LOGIC1.2, U_BUZZ1.1, U_HAPTIC1.6, U_HAPTIC1.10

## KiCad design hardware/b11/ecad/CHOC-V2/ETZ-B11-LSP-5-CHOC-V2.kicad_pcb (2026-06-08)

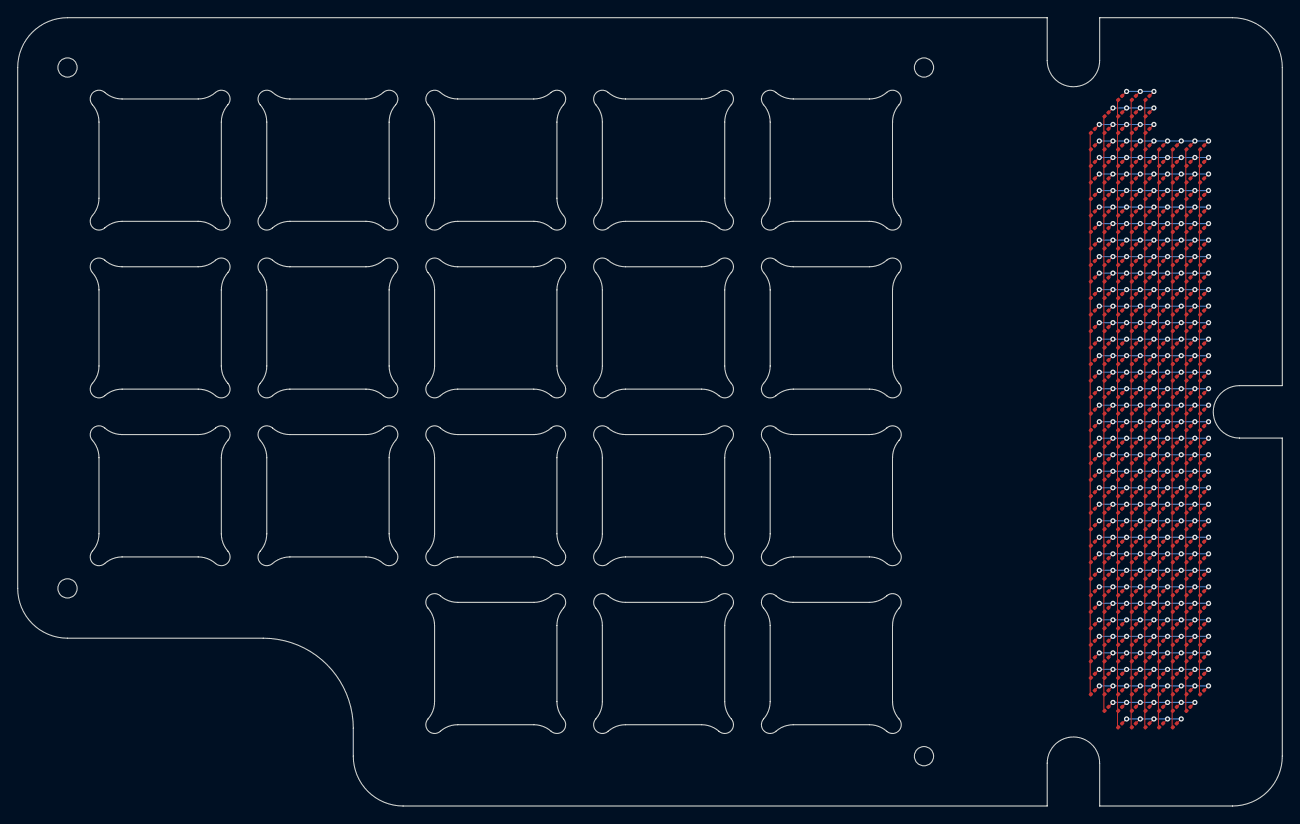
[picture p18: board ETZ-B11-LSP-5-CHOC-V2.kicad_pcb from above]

Board: 2 copper layers, 144.7 x 90.2 mm, 330 parts (0 on the bottom side), 48 nets.

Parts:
D1, D2, D3, D4, D5, D6, D7, D8, D9, D10, D11, D12, D13, D14, D15, D16, D17, D18, D19, D20, D21, D22, D23, D24, D25, D26, D27, D28, D29, D30, D31, D32, D33, D34, D35, D36, D37, D38, D39, D40, D41, D42, D43, D44, D45, D46, D47, D48, D49, D50, D51, D52, D53, D54, D55, D56, D57, D58, D59, D60, D61, D62, D63, D64, D65, D66, D67, D68, D69, D70, D71, D72, D73, D74, D75, D76, D77, D78, D79, D80, D81, D82, D83, D84, D85, D86, D87, D88, D89, D90, D91, D92, D93, D94, D95, D96, D97, D98, D99, D100, D101, D102, D103, D104, D105, D106, D107, D108, D109, D110, D111, D112, D113, D114, D115, D116, D117, D118, D119, D120, D121, D122, D123, D124, D125, D126, D127, D128, D129, D130, D131, D132, D133, D134, D135, D136, D137, D138, D139, D140, D141, D142, D143, D144, D145, D146, D147, D148, D149, D150, D151, D152, D153, D154, D155, D156, D157, D158, D159, D160, D161, D162, D163, D164, D165, D166, D167, D168, D169, D170, D171, D172, D173, D174, D175, D176, D177, D178, D179, D180, D181, D182, D183, D184, D185, D186, D187, D188, D189, D190, D191, D192, D193, D194, D195, D196, D197, D198, D199, D200, D201, D202, D203, D204, D205, D206, D207, D208, D209, D210, D211, D212, D213, D214, D215, D216, D217, D218, D219, D220, D221, D222, D223, D224, D225, D226, D227, D228, D229, D230, D231, D232, D233, D234, D235, D236, D237, D238, D239, D240, D241, D242, D243, D244, D245, D246, D247, D248, D249, D250, D251, D252, D253, D254, D255, D256, D257, D258, D259, D260, D261, D262, D263, D264, D265, D266, D267, D268, D269, D270, D271, D272, D273, D274, D275, D276, D277, D278, D279, D280, D281, D282, D283, D284, D285, D286, D287, D288, D289, D290, D291, D292, D293, D294, D295, D296, D297, D298, D299, D300, D301, D302, D303, D304, D305, D306, D307, D308, D309, D310, D311, D312, D313, D314, D315, D316, D317, D318, D319, D320, D321, D322, D323, D324, D325, D326, D327, D328, D329, D330: 0201_LED

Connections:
LED_CS1: D1.1, D2.1, D3.1
LED_CS2: D4.1, D5.1, D6.1, D7.1
LED_CS3: D8.1, D9.1, D10.1, D11.1, D12.1
LED_CS4: D13.1, D14.1, D15.1, D16.1, D17.1, D18.1, D19.1, D20.1, D21.1
LED_CS5: D22.1, D23.1, D24.1, D25.1, D26.1, D27.1, D28.1, D29.1, D30.1
LED_CS6: D31.1, D32.1, D33.1, D34.1, D35.1, D36.1, D37.1, D38.1, D39.1
LED_CS7: D40.1, D41.1, D42.1, D43.1, D44.1, D45.1, D46.1, D47.1, D48.1
LED_CS8: D49.1, D50.1, D51.1, D52.1, D53.1, D54.1, D55.1, D56.1, D57.1
LED_CS9: D58.1, D59.1, D60.1, D61.1, D62.1, D63.1, D64.1, D65.1, D66.1
LED_CS10: D67.1, D68.1, D69.1, D70.1, D71.1, D72.1, D73.1, D74.1, D75.1
LED_CS11: D76.1, D77.1, D78.1, D79.1, D80.1, D81.1, D82.1, D83.1, D84.1
LED_CS12: D85.1, D86.1, D87.1, D88.1, D89.1, D90.1, D91.1, D92.1, D93.1
LED_CS13: D94.1, D95.1, D96.1, D97.1, D98.1, D99.1, D100.1, D101.1, D102.1
LED_CS14: D103.1, D104.1, D105.1, D106.1, D107.1, D108.1, D109.1, D110.1, D111.1
LED_CS15: D112.1, D113.1, D114.1, D115.1, D116.1, D117.1, D118.1, D119.1, D120.1
LED_CS16: D121.1, D122.1, D123.1, D124.1, D125.1, D126.1, D127.1, D128.1, D129.1
LED_CS17: D130.1, D131.1, D132.1, D133.1, D134.1, D135.1, D136.1, D137.1, D138.1
LED_CS18: D139.1, D140.1, D141.1, D142.1, D143.1, D144.1, D145.1, D146.1, D147.1
LED_CS19: D148.1, D149.1, D150.1, D151.1, D152.1, D153.1, D154.1, D155.1, D156.1
LED_CS20: D157.1, D158.1, D159.1, D160.1, D161.1, D162.1, D163.1, D164.1, D165.1
LED_CS21: D166.1, D167.1, D168.1, D169.1, D170.1, D171.1, D172.1, D173.1, D174.1
LED_CS22: D175.1, D176.1, D177.1, D178.1, D179.1, D180.1, D181.1, D182.1, D183.1
LED_CS23: D184.1, D185.1, D186.1, D187.1, D188.1, D189.1, D190.1, D191.1, D192.1
LED_CS24: D193.1, D194.1, D195.1, D196.1, D197.1, D198.1, D199.1, D200.1, D201.1
LED_CS25: D202.1, D203.1, D204.1, D205.1, D206.1, D207.1, D208.1, D209.1, D210.1
LED_CS26: D211.1, D212.1, D213.1, D214.1, D215.1, D216.1, D217.1, D218.1, D219.1
LED_CS27: D220.1, D221.1, D222.1, D223.1, D224.1, D225.1, D226.1, D227.1, D228.1
LED_CS28: D229.1, D230.1, D231.1, D232.1, D233.1, D234.1, D235.1, D236.1, D237.1
LED_CS29: D238.1, D239.1, D240.1, D241.1, D242.1, D243.1, D244.1, D245.1, D246.1
LED_CS30: D247.1, D248.1, D249.1, D250.1, D251.1, D252.1, D253.1, D254.1, D255.1
LED_CS31: D256.1, D257.1, D258.1, D259.1, D260.1, D261.1, D262.1, D263.1, D264.1
LED_CS32: D265.1, D266.1, D267.1, D268.1, D269.1, D270.1, D271.1, D272.1, D273.1
LED_CS33: D274.1, D275.1, D276.1, D277.1, D278.1, D279.1, D280.1, D281.1, D282.1
LED_CS34: D283.1, D284.1, D285.1, D286.1, D287.1, D288.1, D289.1, D290.1, D291.1
LED_CS35: D292.1, D293.1, D294.1, D295.1, D296.1, D297.1, D298.1, D299.1, D300.1
LED_CS36: D301.1, D302.1, D303.1, D304.1, D305.1, D306.1, D307.1, D308.1, D309.1
LED_CS37: D310.1, D311.1, D312.1, D313.1, D314.1, D315.1, D316.1, D317.1, D318.1
LED_CS38: D319.1, D320.1, D321.1, D322.1, D323.1, D324.1, D325.1
LED_CS39: D326.1, D327.1, D328.1, D329.1, D330.1
LED_SW1: D8.2, D13.2, D22.2, D31.2, D40.2, D49.2, D58.2, D67.2, D76.2, D85.2, D94.2, D103.2, D112.2, D121.2, D130.2, D139.2, D148.2, D157.2, D166.2, D175.2, D184.2, D193.2, D202.2, D211.2, D220.2, D229.2, D238.2, D247.2, D256.2, D265.2, D274.2, D283.2, D292.2, D301.2, D310.2
LED_SW2: D4.2, D9.2, D14.2, D23.2, D32.2, D41.2, D50.2, D59.2, D68.2, D77.2, D86.2, D95.2, D104.2, D113.2, D122.2, D131.2, D140.2, D149.2, D158.2, D167.2, D176.2, D185.2, D194.2, D203.2, D212.2, D221.2, D230.2, D239.2, D248.2, D257.2, D266.2, D275.2, D284.2, D293.2, D302.2, D311.2, D319.2
LED_SW3: D1.2, D5.2, D10.2, D15.2, D24.2, D33.2, D42.2, D51.2, D60.2, D69.2, D78.2, D87.2, D96.2, D105.2, D114.2, D123.2, D132.2, D141.2, D150.2, D159.2, D168.2, D177.2, D186.2, D195.2, D204.2, D213.2, D222.2, D231.2, D240.2, D249.2, D258.2, D267.2, D276.2, D285.2, D294.2, D303.2, D312.2, D320.2, D326.2
LED_SW4: D2.2, D6.2, D11.2, D16.2, D25.2, D34.2, D43.2, D52.2, D61.2, D70.2, D79.2, D88.2, D97.2, D106.2, D115.2, D124.2, D133.2, D142.2, D151.2, D160.2, D169.2, D178.2, D187.2, D196.2, D205.2, D214.2, D223.2, D232.2, D241.2, D250.2, D259.2, D268.2, D277.2, D286.2, D295.2, D304.2, D313.2, D321.2, D327.2
LED_SW5: D3.2, D7.2, D12.2, D17.2, D26.2, D35.2, D44.2, D53.2, D62.2, D71.2, D80.2, D89.2, D98.2, D107.2, D116.2, D125.2, D134.2, D143.2, D152.2, D161.2, D170.2, D179.2, D188.2, D197.2, D206.2, D215.2, D224.2, D233.2, D242.2, D251.2, D260.2, D269.2, D278.2, D287.2, D296.2, D305.2, D314.2, D322.2, D328.2
LED_SW6: D18.2, D27.2, D36.2, D45.2, D54.2, D63.2, D72.2, D81.2, D90.2, D99.2, D108.2, D117.2, D126.2, D135.2, D144.2, D153.2, D162.2, D171.2, D180.2, D189.2, D198.2, D207.2, D216.2, D225.2, D234.2, D243.2, D252.2, D261.2, D270.2, D279.2, D288.2, D297.2, D306.2, D315.2, D323.2, D329.2
LED_SW7: D19.2, D28.2, D37.2, D46.2, D55.2, D64.2, D73.2, D82.2, D91.2, D100.2, D109.2, D118.2, D127.2, D136.2, D145.2, D154.2, D163.2, D172.2, D181.2, D190.2, D199.2, D208.2, D217.2, D226.2, D235.2, D244.2, D253.2, D262.2, D271.2, D280.2, D289.2, D298.2, D307.2, D316.2, D324.2, D330.2
LED_SW8: D20.2, D29.2, D38.2, D47.2, D56.2, D65.2, D74.2, D83.2, D92.2, D101.2, D110.2, D119.2, D128.2, D137.2, D146.2, D155.2, D164.2, D173.2, D182.2, D191.2, D200.2, D209.2, D218.2, D227.2, D236.2, D245.2, D254.2, D263.2, D272.2, D281.2, D290.2, D299.2, D308.2, D317.2, D325.2
LED_SW9: D21.2, D30.2, D39.2, D48.2, D57.2, D66.2, D75.2, D84.2, D93.2, D102.2, D111.2, D120.2, D129.2, D138.2, D147.2, D156.2, D165.2, D174.2, D183.2, D192.2, D201.2, D210.2, D219.2, D228.2, D237.2, D246.2, D255.2, D264.2, D273.2, D282.2, D291.2, D300.2, D309.2, D318.2

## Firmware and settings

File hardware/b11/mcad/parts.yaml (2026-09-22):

# Lists etzee part numbers to be exported by the MCAD manufacturing workflow.
# Part numbers must match the partNumber property set in OnShape
# (right-click a part → Properties → Part Number).
# Only parts listed here will be exported.
#
# build:   common  → exported once, filename is the part number
#          matrix  → exported once per board variant, filename gets the board variant suffix (e.g. -5-MX)
# formats: step    → STEP file (3D and PCB outline source)
#          stl     → STL file (3D printing)
#
# PCB outlines are derived from STEP exports by hardware/b11/tools/generation/fetch-outlines.py:
#   common PCB outlines          → hardware/b11/mcad/pcb-outlines/common/
#   switch-family PCB outlines   → hardware/b11/mcad/pcb-outlines/{MX,CHOC-V2,KS-33}/

parts:

  # common parts — exported once, no board variant suffix
  - part_number: ETZ-B11-TC       # Top cap
    formats: [step, stl]
    build: common

  - part_number: ETZ-B11-LLB      # Left logic board PCB
    formats: [step, stl]
    build: common

  - part_number: ETZ-B11-RLB      # Right logic board PCB
    formats: [step, stl]
    build: common

  - part_number: ETZ-B11-DSP      # Display PCB
    formats: [step, stl]
    build: common

  # matrix parts — exported once per board variant (5-MX, 5-CHOC-V2, 5-KS-33, etc.)
  - part_number: ETZ-B11-LB       # Left base
    formats: [step, stl]
    build: matrix

  - part_number: ETZ-B11-RB       # Right base
    formats: [step, stl]
    build: matrix

  - part_number: ETZ-B11-LSP      # Left switch plate PCB
    formats: [step, stl]
    build: matrix

  - part_number: ETZ-B11-RSP      # Right switch plate PCB
    formats: [step, stl]
    build: matrix

  - part_number: ETZ-B11-LSC      # Left switch carrier PCB
    formats: [step, stl]
    build: matrix

  - part_number: ETZ-B11-RSC      # Right switch carrier PCB
    formats: [step, stl]
    build: matrix

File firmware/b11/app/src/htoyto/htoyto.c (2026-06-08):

#include <stdbool.h>
#include <stdio.h>
#include <string.h>

#include <zephyr/kernel.h>
#include <zephyr/device.h>
#include <zephyr/drivers/gpio.h>
#include <zephyr/drivers/uart.h>
#include <zephyr/logging/log.h>

#include <htoyto/htoyto.h>
#include <htoyto/events/event.h>

LOG_MODULE_REGISTER(htoyto, CONFIG_ZMK_LOG_LEVEL);

#define HTY_NODE     DT_NODELABEL(htoyto0)
#define HTY_ROLE_IDX DT_ENUM_IDX(HTY_NODE, role)
#define HTY_BUF_SIZE (CONFIG_HTOYTO_MAX_NODE_ID_LENGTH * 3 + 16)

typedef enum {
    HTOYTO_STATE_IDLE,
    HTOYTO_STATE_HLO_SENT,      // origin: sent HLO, waiting for IAM
    HTOYTO_STATE_IAM_RECEIVED,  // origin: received IAM, sent EST, waiting for EST echo
    HTOYTO_STATE_EST_SENT,      // terminal: sent IAM, waiting for EST from origin
    HTOYTO_STATE_CONNECTED,
} htoyto_state_t;

static const struct device    *uart_dev;
static struct k_work_delayable handshake_timeout_work;
static struct k_work           rx_process_work;
static htoyto_state_t          state         = HTOYTO_STATE_IDLE;
static bool                    node_connected = false;
static char                    peer_node_id[CONFIG_HTOYTO_MAX_NODE_ID_LENGTH + 1];

#if CONFIG_HTOYTO_KEEPALIVE_MS > 0
static struct k_work_delayable kal_watchdog_work;

#if HTY_ROLE_IDX == 0 || HTY_ROLE_IDX == 1 /* origin or bridge */
static struct k_work_delayable kal_tx_work;
#endif
#endif

static uint8_t tx_buf[HTY_BUF_SIZE];
static int     tx_pos;
static int     tx_len;

// RX accumulation (ISR) → frame_buf (workqueue)
// TODO: replace frame_buf with a ring buffer to handle back-to-back frames
static char     rx_buf[HTY_BUF_SIZE];
static int      rx_pos;
static char frame_buf[HTY_BUF_SIZE];

static void uart_send(const char *str) {
    int len = strlen(str);
    if (len >= HTY_BUF_SIZE) {
        LOG_WRN("TX frame too long, dropping");
        return;
    }
    memcpy(tx_buf, str, len);
    tx_pos = 0;
    tx_len = len;
    uart_irq_tx_enable(uart_dev);
}

static void process_frame(const char *line) {
    if (strncmp(line, "HLO ", 4) == 0) {
        if (state != HTOYTO_STATE_IDLE) {
            LOG_WRN("HLO unexpected in state %d", state);
            return;
        }
        LOG_INF("HLO from %s, sending IAM", line + 4);
        uart_send("IAM " DT_PROP(HTY_NODE, node_id) "\n");
        state = HTOYTO_STATE_EST_SENT;
        k_work_reschedule(&handshake_timeout_work,
                          K_MSEC(CONFIG_HTOYTO_HANDSHAKE_TIMEOUT_MS));

    } else if (strncmp(line, "IAM ", 4) == 0) {
        if (state != HTOYTO_STATE_HLO_SENT) {
            LOG_WRN("IAM unexpected in state %d", state);
            return;
        }
        LOG_INF("IAM from %s, sending EST", line + 4);
        uart_send("EST " DT_PROP(HTY_NODE, node_id) "\n");
        state = HTOYTO_STATE_IAM_RECEIVED;
        k_work_reschedule(&handshake_timeout_work,
                          K_MSEC(CONFIG_HTOYTO_HANDSHAKE_TIMEOUT_MS));

    } else if (strncmp(line, "EST ", 4) == 0) {
        if (state == HTOYTO_STATE_IAM_RECEIVED) {
            LOG_INF("EST from %s — connected (origin)", line + 4);
            strncpy(peer_node_id, line + 4, CONFIG_HTOYTO_MAX_NODE_ID_LENGTH);
            peer_node_id[CONFIG_HTOYTO_MAX_NODE_ID_LENGTH] = '\0';
            k_work_cancel_delayable(&handshake_timeout_work);
            node_connected = true;
            state = HTOYTO_STATE_CONNECTED;
#if CONFIG_HTOYTO_KEEPALIVE_MS > 0 && (HTY_ROLE_IDX == 0 || HTY_ROLE_IDX == 1)
            k_work_reschedule(&kal_tx_work, K_MSEC(CONFIG_HTOYTO_KEEPALIVE_MS));
#endif
            htoyto_emit_node_added(peer_node_id);
        } else if (state == HTOYTO_STATE_EST_SENT) {
            LOG_INF("EST from %s — echoing EST, connected (terminal)", line + 4);
            strncpy(peer_node_id, line + 4, CONFIG_HTOYTO_MAX_NODE_ID_LENGTH);
            peer_node_id[CONFIG_HTOYTO_MAX_NODE_ID_LENGTH] = '\0';
            uart_send("EST " DT_PROP(HTY_NODE, node_id) "\n");
            k_work_cancel_delayable(&handshake_timeout_work);
            node_connected = true;
            state = HTOYTO_STATE_CONNECTED;
#if CONFIG_HTOYTO_KEEPALIVE_MS > 0
            k_work_reschedule(&kal_watchdog_work,
                              K_MSEC(CONFIG_HTOYTO_KEEPALIVE_MS * 3));
#endif
            htoyto_emit_node_added(peer_node_id);
        } else {
            LOG_WRN("EST unexpected in state %d", state);
        }

    } else if (strncmp(line, "KAL ", 4) == 0) {
#if CONFIG_HTOYTO_KEEPALIVE_MS > 0
        if (state == HTOYTO_STATE_CONNECTED) {
            k_work_reschedule(&kal_watchdog_work,
                              K_MSEC(CONFIG_HTOYTO_KEEPALIVE_MS * 3));
        }
#endif

    } else if (strncmp(line, "DKW ", 4) == 0) {
        LOG_WRN("DKW (rejected): %s", line + 4);
        k_work_cancel_delayable(&handshake_timeout_work);
        state = HTOYTO_STATE_IDLE;
        htoyto_emit_node_rejected(DT_PROP(HTY_NODE, node_id), line + 4);

    } else if (strncmp(line, "TLK ", 4) == 0) {
        if (state != HTOYTO_STATE_CONNECTED) {
            LOG_WRN("TLK while not connected");
            return;
        }
        char *src = (char *)(line + 4);
        char *tgt = strchr(src, ',');
        char *pay = tgt ? strchr(tgt + 1, ',') : NULL;
        if (!tgt || !pay) {
            LOG_WRN("malformed TLK: %s", line);
            return;
        }
        *tgt++ = '\0';
        *pay++ = '\0';
        htoyto_emit_tlk_received(src, tgt, pay);

    } else if (strncmp(line, "ACK ", 4) == 0) {
        if (state == HTOYTO_STATE_CONNECTED) {
            LOG_DBG("ACK: %s", line + 4);
            htoyto_emit_ack_received(DT_PROP(HTY_NODE, node_id));
        }

    } else {
        LOG_WRN("unknown frame: %s", line);
    }
}

static void rx_process_handler(struct k_work *work) {
    process_frame(frame_buf);
}

static void uart_irq_handler(const struct device *dev, void *user_data) {
    if (!uart_irq_update(dev)) return;

    if (uart_irq_tx_ready(dev)) {
        if (tx_pos < tx_len) {
            int sent = uart_fifo_fill(dev, tx_buf + tx_pos, tx_len - tx_pos);
            tx_pos += sent;
        }
        if (tx_pos >= tx_len) {
            uart_irq_tx_disable(dev);
        }
    }

    if (uart_irq_rx_ready(dev)) {
        uint8_t c;
        while (uart_fifo_read(dev, &c, 1) == 1) {
            if (c == '\n' || c == '\r') {
                if (rx_pos > 0) {
                    rx_buf[rx_pos] = '\0';
                    strncpy(frame_buf, rx_buf, HTY_BUF_SIZE - 1);
                    frame_buf[HTY_BUF_SIZE - 1] = '\0';
                    rx_pos = 0;
                    k_work_submit(&rx_process_work);
                }
            } else if (rx_pos < HTY_BUF_SIZE - 1) {
                rx_buf[rx_pos++] = c;
            } else {
                LOG_WRN("RX overflow, dropping frame");
                rx_pos = 0;
            }
        }
    }
}
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

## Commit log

2025-04-08 chore: batman
    [Keyboard parts - Display PCB.dxf, Keyboard parts - L PCB.dxf, Keyboard parts - L Pogo pin PCB.dxf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]
2025-04-08 Added initial placement for MX switches
    [le-board.kicad_pcb, le-board.kicad_sch]
2025-04-20 chore: minor updates
    [BL.stl, BR.stl, CC.stl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]
2025-04-22 Added keyboard_pad_left, keyboard_pad_right. Added LDOs, Added USB C connector. Added initial placement for keys.
    [keyboard_pad_left.kicad_sch, keyboard_pad_right.kicad_sch, le-board.kicad_pcb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]
2025-04-22 chore: move screw mounting points
    [BL.stl, BR.stl, PCBL.dxf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]
2025-04-22 chore: PCB dimesnions change
    [BL.stl, BR.stl, PCBL.dxf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]
2025-04-26 Added step model for reference
    [le-board.step]
2025-04-30 chore: add detail pcb outline
    [le-board.kicad_pcb]
2025-04-30 chore: added issing files
    [Detail PCB.dxf]
2025-05-01 chore: pcb outline export
    [Detail PCB.dxf, PCBL.dxf, PCBR.dxf]
2025-05-01 chore: pcb update
    [le-board.kicad_pcb]
2025-05-02 feat: wave coil script
    [PCBDMD.dxf, PCBLM.dxf, PCBRM.dxf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]
2025-05-06 chore: generated PCB stator
    [le-board.kicad_pcb]
2025-05-12 chore: wave coils
    [PCBSTR.dxf, le-board.kicad_pcb]
2025-05-14 chore: PCB cut edge updates
    [PCBD.dxf, le-board.kicad_pcb]
2025-05-17 Added drawio diagram for pcb
2025-05-22 chore: automate export of STL files
2025-05-22 chore: parts export
    [BL.stl, BR.stl, CC.stl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]
2025-06-15 chore: add symbolic link to board def
2025-06-24 Added 80% Schematic Finished.
    [le-board.kicad_sch]
2025-06-27 Dodao sam pogo pinove za UART i za BAT(Napajanje za punjenje baterije), i Konektore za programiranje. Nazivi napajanja jos nisu sredjeni nabacano je, treba da se sredi gde sta ide ASAP.
    [le-board.kicad_sch]
2025-07-16 chore: firmware flow update
2025-07-19 feat: started htoyto-zmk protocol 🎉 [no ci]
2025-07-19 feat: htyoto protocol, minimal implementation and first build 🤞
2025-10-27 chore: change repo structure
    [PCBD.dxf, PCBDMD.dxf, PCBL.dxf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]
2026-03-18 chore: add first mcad files
    [etz-b11-bl-n5.stl, etz-b11-tc.step]
2026-03-20 Left side PCB outlines (#21)
    * chore: add left side pcb outlines [no ci]
    * Initial plan (#22)
    ---------
    [etz-b11-lb.dxf, etz-b11-swl-5.dxf, etz-b11-tpl-5.dxf]
2026-04-07 🔧 Add MCAD manufacturing workflow with OnShape integration and matrix builds (#25)
    * Initial plan
    * Add MCAD manufacturing workflow with OnShape integration and matrix builds
    Agent-Logs-Url: https://github.com/secersh/etzee/sessions/e812d314-52bc-496d-9a94-5288efb0dd21
    * Switch to workflow_dispatch only; add parts mapping file; read part IDs from parts.yaml
    Agent-Logs-Url: https://github.com/secersh/etzee/sessions/e54ef271-3778-455e-aeb0-7ae5d7b45b1a
    * Refactor: split mcad.yaml into reusable mcad-export.yaml + per-component mcad-b11.yaml
    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
2026-04-07 fix: pass configuration as URL query param (not JSON body) in STEP/STL translation POST requests (#28)
    Agent-Logs-Url: https://github.com/secersh/etzee/sessions/9065f45c-f76b-4f49-bb20-c01aa69c70ea
2026-04-08 Add release job to mcad-b11 and improve STL export quality (#29)
    Agent-Logs-Url: https://github.com/secersh/etzee/sessions/b3925f3a-1f2c-4af2-84d3-9346e11eccef
2026-04-08 fix: use part names as export filenames and improve STL quality (#30)
    Agent-Logs-Url: https://github.com/secersh/etzee/sessions/8572c829-bbe0-49a1-8245-575b2fdbcd90
2026-04-08 fix: name STEP/STL files inside export artifacts by OnShape part number (#32)
    * fix: name STEP/STL files inside zips by OnShape part number
    Agent-Logs-Url: https://github.com/secersh/etzee/sessions/099f5547-158e-4d4e-a9b3-cae56e06823d
    * fix: upload flat STEP/STL files directly; pack collection zips in release
    Agent-Logs-Url: https://github.com/secersh/etzee/sessions/66529df6-eb43-49d9-afee-1b8390523b09
    ---------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
2026-04-08 fix: restore STEP/STL extraction and renaming by OnShape part number (#33)
    * Revert "fix: name STEP/STL files inside export artifacts by OnShape part numb…"
    This reverts commit 828f057f53eeb7cf0737ff8994228c96c43acbf7.
    * fix: restore STEP/STL extraction and renaming by OnShape part number
    Agent-Logs-Url: https://github.com/secersh/etzee/sessions/80bb508f-bd05-415d-8abf-703f934a41be
    * fix: lowercase profile matrix values for all-lowercase artifact names
    Agent-Logs-Url: https://github.com/secersh/etzee/sessions/359bebd5-f318-4a67-a25d-2ad08ca3b5c1
    ----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
2026-04-08 fix: handle multiple STEP/STL files per part zip from OnShape (#34)
    * Revert "fix: restore STEP/STL extraction and renaming by OnShape part number …"
    This reverts commit ef54113d2bfd6d31acb05a4a8096626005d10627.
    * fix: handle multiple STEP/STL files per zip gracefully with numeric suffixes
    Agent-Logs-Url: https://github.com/secersh/etzee/sessions/e17dc90c-f4fd-4006-a2c8-a9e9ef46210f
    * fix: one STEP/STL export request per part so each zip yields exactly one correctly-named file
    Agent-Logs-Url: https://github.com/secersh/etzee/sessions/43f4775d-2392-418f-9fd9-b4871b7b5acc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
2026-04-08 Update logic board part number in parts.yaml
2026-05-23 feat:Organize B11 hardware tooling, generated PCBs, and project governance
    Rework the B11 hardware repository structure around a reproducible generated-PCB workflow.
    This change adds dedicated B11 tooling for generating PCB files from tracked outlines, applying manufacturer stackups and DRU files, and placing switch sockets plus LEDs across
    the supported switch families. Generated B11 outputs are organized by switch family and board variant, with MX, CHOC-V2, and KS-33 variants covered for the current 5-column and 6-
    column boards.
    The hardware libraries are cleaned up by removing stale local/submodule library usage and standardizing the footprints and 3D model locations under the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
    [ETZ-B11-LSC-5-CHOC-V2.dxf, ETZ-B11-LSC-5-CHOC-V2.kicad_pcb, ETZ-B11-LSC-5-KS-33.dxf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]
2026-05-24 Adjust B11 display LED layout [skip ci] (#56)
    [ETZ-B11-LSP-5-CHOC-V2.kicad_pcb, ETZ-B11-LSP-5-KS-33.kicad_pcb, ETZ-B11-LSP-5-MX.kicad_pcb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]
2026-06-08 feat: add B11 display module attach footprint (#57) [no ci]
    * Organize B11 PCB tooling scripts [skip ci]
    * Route B11 display LED matrix [skip ci]
    * Add ETZ-B11-DSP PCB generation support [skip ci]
    * Generate ETZ-B11-DSP display PCB [skip ci]
    * Prototype B11 display driver fanout [skip ci]
    * feat: add B11 display module attach footprint [skip ci]
    * chore: update display component assets [skip ci]
    * feat: add B11 LRA test footprint [skip ci]
    * feat: add B11 buzzer footprint [skip ci]
    * feat: add B11 haptic and pogo connector assets [skip ci]
    * feat: add B11 buzzer h-bridge driver [skip ci]
    * feat: refine B11 display module routin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
    [ETZ-B11-DSP.dxf, ETZ-B11-DSP.kicad_pcb, ETZ-B11-LSP-5-CHOC-V2.kicad_pcb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]
2026-06-08 feat(firmware): b11 board config, htoyto skeleton, CI baseline [WIP] (#47) [no ci]
    * feat(firmware): add b11 ZMK board config and htoyto protocol skeleton
    - Add etzee_b11 board definition (nRF52840, split keyboard)
    - Add DTS, pinctrl, defconfig, Kconfig, keymap, and side overlays
    - Add htoyto protocol source, bindings, headers, and reactor
    - Update firmware.yaml workflow paths from ws-1 to b11
    - Rename board identifier from etzee_101 to etzee_b11
    Refs #39
    * fix(ci): pin ZMK to v0.3-branch, build both left and right sides
    - Clone ZMK at v0.3-branch (Zephyr 3.5) to match our board format
    - Use separate build dirs (build/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
    [htoyto.c]
2026-09-11 feat: add B11 switch plate schematic foundation (#58)
    [ETZ-B11-LSC-5-KS-33.kicad_pcb, ETZ-B11-LSC-6-KS-33.kicad_pcb, ETZ-B11-LSP-6-KS-33.kicad_pcb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]
2026-09-13 feat: add left and right B11 logic board foundations
    [ETZ-B11-LGB-L.dxf, ETZ-B11-LGB-L.kicad_pcb, ETZ-B11-LGB-R.dxf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]
2026-09-13 feat: add Cnomax magnetic connector pair
2026-09-13 chore: remove obsolete connector assets
2026-09-14 feat: add logic board connector placement
    [ETZ-B11-LGB-L.kicad_pcb, ETZ-B11-LGB-R.kicad_pcb]
2026-09-21 feat: add carrier logic FPC interconnect
    [ETZ-B11-LGB-L.kicad_pcb, ETZ-B11-LSC-6-KS-33.kicad_pcb]
2026-09-22 feat: extend B11 carrier and logic board foundations
    [ETZ-B11-LB.kicad_sch, ETZ-B11-LLB.dxf, ETZ-B11-LLB.kicad_pcb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]
2026-09-23 feat: add logic-board locating holes and fabrication rules
    [ETZ-B11-LLB.dxf, ETZ-B11-LLB.kicad_pcb, ETZ-B11-RLB.dxf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]
2026-10-25 feat: complete B11 switch carrier foundation
    Complete the shared switch-carrier schematic and synchronize the KS-33 left carrier board with its matrix, backlight driver, battery input, and FPC interface.\n\nAdd the JST ACH connector assets, sou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
2026-10-31 feat: finalize B11 switch carrier layout
